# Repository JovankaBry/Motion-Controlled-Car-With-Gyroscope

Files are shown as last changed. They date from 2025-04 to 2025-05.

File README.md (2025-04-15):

# Embedded-System-Project
A motion-controlled car project using an MPU6050 gyroscope connected via wire to an Arduino, where hand tilts control the car’s direction.

How It Works:
- An MPU6050 sensor is mounted on a glove or handheld controller.
- The sensor detects the tilt of the hand (pitch and roll).
- These tilt values are sent to the Arduino over a wired connection (I2C).
- Based on the detected angle, the Arduino processes the data and controls the car's direction:
  - Tilt left → car turns left
  - Tilt right → car turns right
  - Tilt forward → car moves forward
  - Tilt backward → car reverses

Components Used:
-Arduino Nano
- MPU6050 Gyroscope & Accelerometer Module
- Motor Driver (e.g., L298N or similar)
- DC motors with wheels
- Battery 9V
- Jumper wires
- Chassis or 3D printed body

Features:
-Real-time motion control using hand gestures
-Wired I2C communication for low latency
-Simple and intuitive control system
-Expandable for wireless control (e.g., using NRF24L01 or Bluetooth)

Library:
For the sensor MPU-6050 a library is needed and the right library for that is MPU6050_Light from rfetick "https://github.com/rfetick/MPU6050_light"

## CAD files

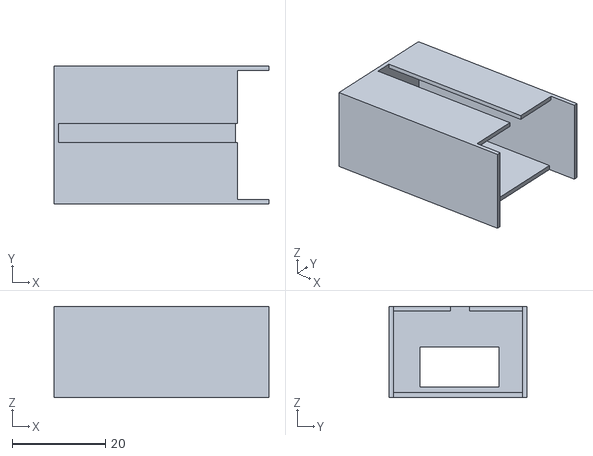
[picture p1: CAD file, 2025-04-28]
CAD-3D Parts/Additional Parts/Battery Pack.stl
46.0 x 29.5 x 19.5

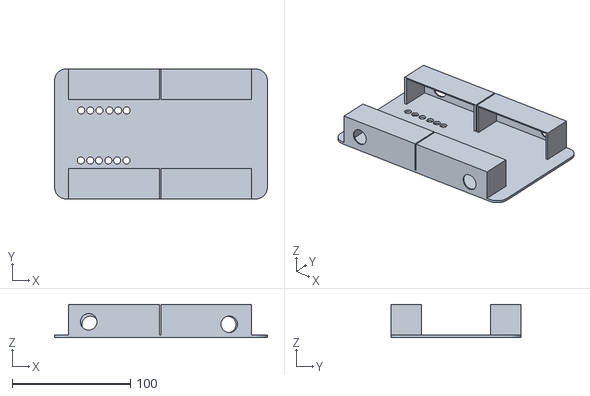
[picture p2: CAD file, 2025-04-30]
CAD-3D Parts/Prototype V2/Prototype V2.stl
180.0 x 110.0 x 28.0

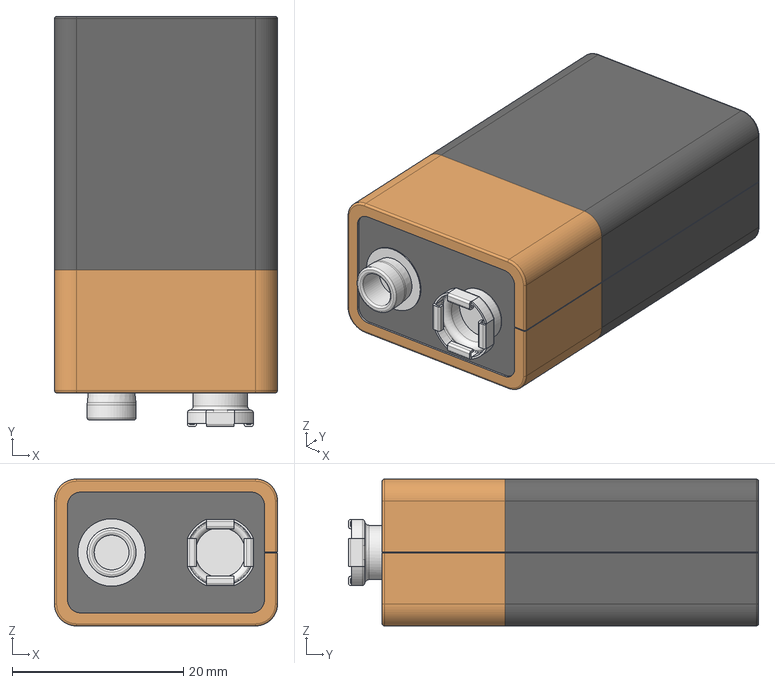
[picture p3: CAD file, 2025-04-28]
CAD-3D Parts/Additional Parts/9V-battery.stp
26.0 x 47.9 x 17.1 mm

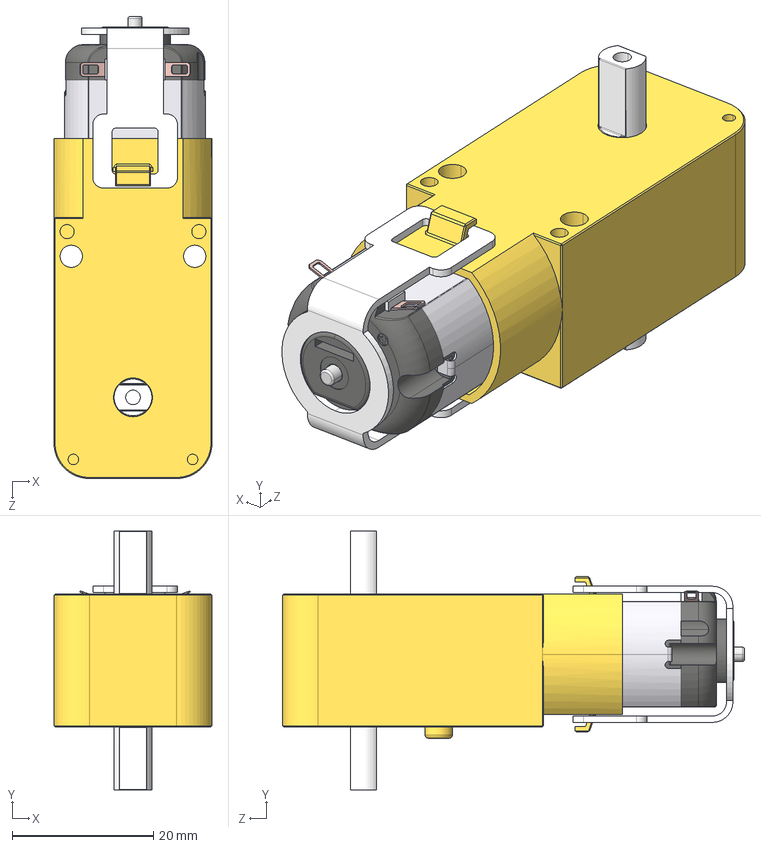
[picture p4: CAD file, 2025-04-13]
CAD-3D Parts/Additional Parts/Mini Gear DC Motor 6 V Yellow.STEP
22.4 x 36.7 x 65.5 mm
dc motor.stp
Nody
Axe
Belt

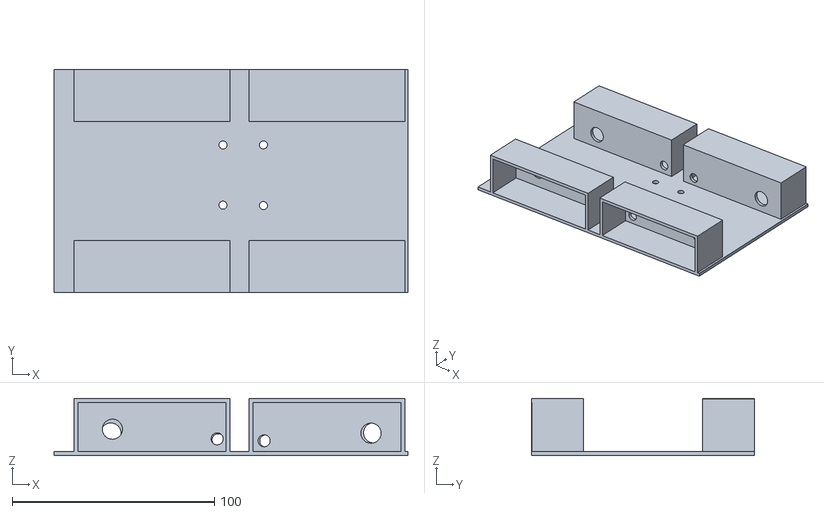
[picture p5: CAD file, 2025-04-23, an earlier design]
CAD-3D Parts/Prototype V1/Prototype1.stl
175.0 x 110.0 x 28.4

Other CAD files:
CAD-3D Parts/Transmitter Case/Transmitter case.dwg
CAD-3D Parts/Prototype V1/Protoype1.dwg
CAD-3D Parts/Prototype V2/Prototype V2.dwg

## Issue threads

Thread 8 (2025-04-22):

Reset Button must be added to MCU

JovankaBry, 2025-04-22:

JovankaBry, 2025-04-22:
button must be connected to RESET pin from MCU

JovankaBry, 2025-04-28:
reset button is not needed, considering the ardino nano isnt closed at all!

Closed 2025-04-28.

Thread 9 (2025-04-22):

On & Off

JovankaBry, 2025-04-22:
adding button/transistor/switch, so the motor can be deactivated

JovankaBry, 2025-04-24:
The idea is to use 1 transistor, and when a button is pressed, current flows through Base (PIN 2), ensuring the connection between Collector and Emitter

JovankaBry, 2025-04-24:
const int buttonPin = 6;
const int ledPin = 4;
int ledState = LOW;
int lastButtonState = HIGH;

void setup() {
  pinMode(ledPin, OUTPUT);
  pinMode(buttonPin, INPUT_PULLUP);
  digitalWrite(ledPin, ledState);
}

void loop() {
  int currentButtonState = digitalRead(buttonPin);

  if (lastButtonState == HIGH && currentButtonState == LOW) {
    ledState = !ledState;
    digitalWrite(ledPin, ledState);
    delay(200); // Simple debounce delay
  }

  lastButtonState = currentButtonState;
}

Closed 2025-05-07.

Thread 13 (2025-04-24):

Start to make Schematic

JovankaBry, 2025-04-24:
Schematic needs to be ordered around the middle of May

JovankaBry, 2025-04-24:
It can be ordered through. The price of the first order is 5€[Next PCB](https://www.nextpcb.com/pcb-quote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)

JovankaBry, 2025-04-24:
or [PCB Way](https://www.pcbway.com/orderonline.aspx)

JovankaBry, 2025-04-28:
started to make schamatic, need to be rechecked

Closed 2025-04-28.

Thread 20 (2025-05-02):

9V Battery Issues

JovankaBry, 2025-05-02:
idea is to change 9v batterie to 1.5v in series battery

Closed 2025-05-07.

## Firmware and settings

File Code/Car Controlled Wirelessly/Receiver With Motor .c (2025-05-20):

#include <SPI.h>
#include <nRF24L01.h>
#include <RF24.h>

RF24 radio(7, 8); // CE, CSN pins
const byte address[6] = "00001";

// Motor pins (using your exact setup)
const int motor1 = 2;
const int motor2 = 3;
const int motor3 = 5;
const int motor4 = 6;

struct GyroData {
  float angleX; // Left/Right tilt
  float angleY; // Forward/Backward tilt
};

void setup() {
  Serial.begin(9600);
  
  // Initialize motor pins
  pinMode(motor1, OUTPUT);
  pinMode(motor2, OUTPUT);
  pinMode(motor3, OUTPUT);
  pinMode(motor4, OUTPUT);
  
  // Initialize radio
  radio.begin();
  radio.openReadingPipe(0, address);
  radio.setPALevel(RF24_PA_MIN);
  radio.startListening();

  Serial.println("System Ready");
}

void stopMotors() {
  digitalWrite(motor1, LOW);
  digitalWrite(motor2, LOW);
  digitalWrite(motor3, LOW);
  digitalWrite(motor4, LOW);
}

void moveForward() {
  // Your exact forward pattern
  digitalWrite(motor1, LOW);
  digitalWrite(motor2, HIGH);
  digitalWrite(motor3, HIGH);
  digitalWrite(motor4, LOW);
  Serial.println("Moving Forward");
}

void moveForwardRight() {
  // Nyalakan roda depan kiri dulu
  digitalWrite(motor1, LOW);   // Depan kiri maju
  digitalWrite(motor2, HIGH);  // Belakang kiri mundur (untuk maju)
  
  // Delay sebentar sebelum nyalakan roda kanan
  delay(100); // Delay 100ms

  digitalWrite(motor3, HIGH);  // Depan kanan maju
  digitalWrite(motor4, LOW);   // Belakang kanan mundur (untuk maju)

  Serial.println("Moving Forward Right (dengan delay motor3)");
}

void moveForwardLeft() {
  // Nyalakan sisi kanan dulu
  digitalWrite(motor3, HIGH);  // Depan kanan maju
  digitalWrite(motor4, LOW);   // Belakang kanan bantu maju

  delay(100); // Delay sebelum sisi kiri nyala

  digitalWrite(motor1, LOW);   // Depan kiri maju
  digitalWrite(motor2, HIGH);  // Belakang kiri bantu maju

  Serial.println("Moving Forward Left");
}

void moveBackward() {
  // Inverse of your forward pattern
  digitalWrite(motor1, HIGH);
  digitalWrite(motor2, LOW);
  digitalWrite(motor3, LOW);
  digitalWrite(motor4, HIGH);
  Serial.println("Moving Backward");
}

void moveBackwardRight() {
  // Nyalakan sisi kiri dulu (mundur)
  digitalWrite(motor1, HIGH);  // Depan kiri mundur
  digitalWrite(motor2, LOW);   // Belakang kiri bantu mundur

  delay(100); // Delay sebelum sisi kanan nyala

  digitalWrite(motor3, LOW);   // Depan kanan mundur
  digitalWrite(motor4, HIGH);  // Belakang kanan bantu mundur

  Serial.println("Moving Backward Right");
}

void moveBackwardLeft() {
  // Nyalakan sisi kanan dulu (mundur)
  digitalWrite(motor3, LOW);   // Depan kanan mundur
  digitalWrite(motor4, HIGH);  // Belakang kanan bantu mundur

  delay(100); // Delay sebelum sisi kiri nyala

  digitalWrite(motor1, HIGH);  // Depan kiri mundur
  digitalWrite(motor2, LOW);   // Belakang kiri bantu mundur

  Serial.println("Moving Backward Left");
}

void turnRight() {
  // Left side forward, right side backward (sharp turn)
  digitalWrite(motor1, LOW);
  digitalWrite(motor2, HIGH);
  digitalWrite(motor3, LOW);
  digitalWrite(motor4, HIGH);
  Serial.println("Turning Right");
}

void turnLeft() {
  // Right side forward, left side backward (sharp turn)
  digitalWrite(motor1, HIGH);
  digitalWrite(motor2, LOW);
  digitalWrite(motor3, HIGH);
  digitalWrite(motor4, LOW);
  Serial.println("Turning Left");
}

void loop() {
  if (radio.available()) {
    GyroData data;
    radio.read(&data, sizeof(data));

    // Invert angleY to fix left/right confusion
    data.angleY = -data.angleY;

    stopMotors();

    // angleX = forward/backward tilt
    // angleY = left/right tilt
    if (data.angleX > 15 && data.angleY > 15) {
      moveForwardRight();
    }
    else if (data.angleX > 15 && data.angleY < -15) {
      moveForwardLeft();
    }
    else if (data.angleX < -15 && data.angleY > 15) {
      moveBackwardRight();
    }
    else if (data.angleX < -15 && data.angleY < -15) {
      moveBackwardLeft();
    }
    else if (data.angleX > 15) {
      moveForward();
    }
    else if (data.angleX < -15) {
      moveBackward();
    }
    else if (data.angleY > 15) {
      turnRight();
    }
    else if (data.angleY < -15) {
      turnLeft();
    }
    else {
      stopMotors();
      Serial.println("Stopped");
    }
  }
}

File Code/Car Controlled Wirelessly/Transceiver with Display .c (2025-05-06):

#include <SPI.h>
#include <nRF24L01.h>
#include <RF24.h>
#include <Wire.h>
#include <MPU6050_light.h>
#include <U8g2lib.h>

// NRF24 Setup
RF24 radio(7, 8); // CE, CSN for Uno/Nano
const byte address[6] = "00001";

// MPU6050 Setup
MPU6050 mpu(Wire);
unsigned long timer = 0;

// OLED Setup
U8G2_SH1106_128X64_NONAME_1_HW_I2C u8g2(U8G2_R0, /* reset=*/ U8X8_PIN_NONE);

// Button Setup
const int buttonPin = 3; // Button to GND with internal pull-up
unsigned long buttonPressTime = 0;
bool resetTriggered = false;

// Data structure
struct GyroData {
  float angleX;
  float angleY;
  float angleZ;
};

void softReset() {
  asm volatile ("jmp 0"); // Software reset
}

void checkReset() {
  static bool buttonActive = false;
  
  if (digitalRead(buttonPin) == LOW) { // Button pressed
    if (!buttonActive) {
      buttonActive = true;
      buttonPressTime = millis();
    }
    
    // Check if held for 5 seconds
    if (millis() - buttonPressTime > 5000 && !resetTriggered) {
      u8g2.firstPage();
      do {
        u8g2.setFont(u8g2_font_ncenB08_tr);
        u8g2.drawStr(20, 30, "Resetting...");
      } while (u8g2.nextPage());
      delay(500);
      resetTriggered = true;
      softReset();
    }
  } else {
    buttonActive = false;
  }
}

void Introscreen() {
  u8g2.firstPage();
  do {
    u8g2.setFont(u8g2_font_ncenB08_tr);
    u8g2.drawStr(10, 15, "Embedded System");
    u8g2.drawStr(40, 30, "Projekt");
    u8g2.drawStr(35, 45, "Sose 2025");
  } while (u8g2.nextPage());
  delay(2000);
}

void showWelcomeScreen() {
  u8g2.firstPage();
  do {
    u8g2.setFont(u8g2_font_ncenB08_tr);
    u8g2.drawStr(5, 15, "Herzlich Wilkommen");
    u8g2.drawStr(23, 30, "Bitte Druecken");
    u8g2.drawStr(30, 45, "zum Starten");
  } while (u8g2.nextPage());
}

void setup() {
  Serial.begin(9600);
  Wire.begin();
  pinMode(buttonPin, INPUT_PULLUP);

  // Initialize OLED
  u8g2.begin();

  // Initialize MPU6050
  byte status = mpu.begin();
  Serial.print(F("MPU6050 status: "));
  Serial.println(status);
  while(status != 0) { 
    // Show error if MPU fails to initialize
    u8g2.firstPage();
    do {
      u8g2.setFont(u8g2_font_ncenB08_tr);
      u8g2.drawStr(15, 30, "MPU6050 Error!");
      u8g2.drawStr(10, 45, "Check Connection");
    } while (u8g2.nextPage());
    delay(1000);
  }

  Introscreen();

  // Wait for button press to continue
  bool waitingForButton = true;
  while(waitingForButton) {
    checkReset(); // Check for reset during wait
    showWelcomeScreen();
    
    if(digitalRead(buttonPin) == LOW) {
      delay(50); // Debounce
      if(digitalRead(buttonPin) == LOW) {
        waitingForButton = false;
      }
    }
    mpu.update(); // Keep MPU updated
  }

  // Calibration
  Serial.println(F("Calculating offsets, do not move MPU6050"));
  u8g2.firstPage();
  do {
    u8g2.setFont(u8g2_font_ncenB08_tr);
    u8g2.drawStr(5, 30, "Calculating MPU6050");
    u8g2.drawStr(20, 45, "DO NOT MOVE!!!");
  } while (u8g2.nextPage());
  
  delay(1000);
  mpu.calcOffsets();
  Serial.println("Done!\n");

  // Ready message
  u8g2.firstPage();
  do {
    u8g2.setFont(u8g2_font_ncenB08_tr);
    u8g2.drawStr(20, 30, "Device Is Ready");
  } while (u8g2.nextPage());
  delay(2000);

  // Radio initialization
  if (!radio.begin()) {
    Serial.println("Radio initialization failed!");
    u8g2.firstPage();
    do {
      u8g2.setFont(u8g2_font_ncenB08_tr);
      u8g2.drawStr(15, 30, "Radio Error!");
      u8g2.drawStr(10, 45, "Check NRF24");
    } while (u8g2.nextPage());
    while(1); // Halt on radio failure
  }
  Serial.println("Radio initialized successfully");
  radio.openWritingPipe(address);
  radio.setPALevel(RF24_PA_MIN);
  radio.stopListening();
}

void loop() {
  checkReset(); // Continuous reset check
  
  mpu.update();

  if ((millis() - timer) > 20) { // 50Hz update rate
    GyroData data = {mpu.getAngleX(), mpu.getAngleY(), mpu.getAngleZ()};
    bool success = radio.write(&data, sizeof(data));

    // OLED Display Update
    u8g2.firstPage();
    do {
      u8g2.setFont(u8g2_font_6x10_tr);
      u8g2.setCursor(0, 12); 
      u8g2.print("X: "); u8g2.print(data.angleX, 1);
      u8g2.setCursor(0, 24); 
      u8g2.print("Y: "); u8g2.print(data.angleY, 1);
      u8g2.setCursor(0, 36); 
      u8g2.print("Z: "); u8g2.print(data.angleZ, 1);
      u8g2.setCursor(0, 48); 
      u8g2.print("TX: "); u8g2.print(success ? "OK" : "Fail");
    } while (u8g2.nextPage());

    // Serial Monitor Output
    Serial.print("X: ");
    Serial.print(data.angleX);
    Serial.print(" Y: ");
    Serial.print(data.angleY);
    Serial.print(" Z: ");
    Serial.print(data.angleZ);
    Serial.print(" Transmission: ");
    Serial.println(success ? "OK" : "Failed");

    timer = millis();
  }
}

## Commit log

2025-04-13 Create Cad-3D File
    3D Files from CAD for the Project
2025-04-13 DC Motor CAD
2025-04-13 DC Motor 6V CAD 3D
    [Mini Gear DC Motor 6 V Yellow.STEP]
2025-04-13 Made simple board for the project
    the board has 4 small rooms in the bottom size, the rooms are being used for the 4 DC motors,
    [Prototyp1.dwg]
2025-04-13 Delete CAD-3D Parts/test
    ONLY TEST
2025-04-15 Schematic & PCB for the "Piggy Bag" of the Arduino Nano
2025-04-15 Code for direction for Prototype 1
2025-04-15 added turn left while going straight
    added turn left while going straight, because when only LEFT mode is activated, the car will start spinning around, so the motor on the other side need to be adjusted
2025-04-15 Added STL file for 3D Printing
    [Prototyp1.stl]
2025-04-15 Simple Code for turning on LED
2025-04-15 LED turns on when x axis is greater than 10
2025-04-15 Create NRF24L01 wireless module
    code and library needs to be added & made for this project
2025-04-22 Rename Directions to Motor Directions
2025-04-22 Created Prototype1
2025-04-23 Updated 3D files
    [Prototype1.stl, Protoype1.2.dwg]
2025-04-24 Prototype V1
2025-04-24 Created Prototype V1
2025-04-24 Create Prototype V2
2025-04-24 Rename Prototype /Prototype V2 to Prototype /Prototype V2 /About Prototype V2 .txt
2025-04-24 Update and rename te to About Prototype V1 .txt
2025-04-24 These are the following files for Prototype 1
    [Prototype1.stl, Protoype1.dwg]
2025-04-27 Created Prototype 2
2025-04-27 Created Protype 2
    [Prototype2.dwg]
2025-04-27 Added Prototype 2 stl
    [Prototype2.stl]
2025-04-27 Created Prototype2
    [Prototype2.stl]
2025-04-27 added DWG Prototype 2
    [Prototype2.dwg]
2025-04-27 Create Receiver With Motor .c
2025-04-27 Update Receiver With Motor .c
2025-04-28 Added Prototype 2.1
    Seperated Battry pack
    [Prototype 2.1.dwg, Prototype V2.2.stl]
2025-04-28 Added 3D Additional Parts
    [9V-battery.stp, Mini Gear DC Motor 6 V Yellow.STEP]
2025-04-28 Create Prototype V1
2025-04-28 Added Prototype 1
    [Prototype1.stl, Protoype1.dwg]
2025-04-28 Added Prototype 2
    [Prototype V2.dwg, Prototype V2.stl]
2025-04-28 Added Battery pack for Prototype V2
    [Battery Pack.stl]
2025-04-28 Added Prototype V1 Schematic
    [PCB1.PcbDoc, PCB_Motor.PrjPcb, Prototype V1.SchDoc]
2025-04-30 Added Prototype V2
    [Prototype V2.stl]
2025-04-30 Added DWG
    [Prototype V2.dwg]
2025-05-04 Create 3D CAD
2025-05-05 WOrking with Device is Ready in display
2025-05-05 Update Transceiver with Display. c
    added 5s timer for device is ready
2025-05-05 Update Transceiver with Display. c
    Added button to start
2025-05-05 Update Transceiver with Display. c
    Added Button and Reset function
2025-05-07 New codew for prototype V2
2025-05-10 Uploaded Schematic PCB for Transmitter
    [PCB1.PcbDoc, PCB_Motor.PrjPcb, Prototype V1.SchDoc]
2025-05-11 Updatet Schematic for Transmitter
    [PCB1.PcbDoc, PCB_Motor.PrjPcb, Prototype V1.SchDoc]
2025-05-11 Updated Schematic and Layout for Tramitter
    [PCB1.PcbDoc, PCB_Motor.PrjPcb]
2025-05-11 Added .cam Gerber file
2025-05-11 Added Battery Voltage detector
    [PCB1.PcbDoc, PCB_Motor.PrjPcb, Prototype V1.SchDoc]
2025-05-11 Added Gerber File
    [PCB1.GBL, PCB1.GBP, PCB1.GBS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]
2025-05-11 Added PCB Tramitter .step & updated transmitter case.dwg
    [PCB_Motor.PrjPcb]
2025-05-12 Updated Transmitter case.dwg
2025-05-16 Deleted Unneeded file
    [PCB1.PcbDoc, PCB_Motor.PrjPcb, Prototype V1.SchDoc]
2025-05-16 Added Schematic for motor Receiver
    [PCB_Motor_Receiver.PrjPcb, PCB_Receiver.PcbDoc, Receiver.SchDoc]
2025-05-16 Updated Schematic for Receiver with motor
    [PCB_Motor_Receiver.PrjPcb, PCB_Receiver.PcbDoc, Receiver.SchDoc]
2025-05-16 Finished pcb for Motor Receiver
    [PCB_Motor_Receiver.PrjPcb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]
2025-05-20 Updated width +3V3 Width to 1mm
    [PCB1.PcbDoc]
2025-05-20 Added Transmitter V2
    [PCB_Transmitter_V2.PcbDoc, Transmitter V2.PrjPcb, Transmitter V2.SchDoc]
2025-05-20 Schematic finsihed, but needs to be rechecked again
    [Transmitter V2.PrjPcb, Transmitter V2.SchDoc]
2025-05-21 Finished building Transmitter Prototype V2
    [PCB_Transmitter_V2.PcbDoc, Transmitter V2.PrjPcb, Transmitter V2.SchDoc]
2025-05-21 Changed The LED On&Off Status
    [PCB_Transmitter_V2.PcbDoc, Transmitter V2.SchDoc]
2025-05-21 Added Project Outputs for Transmitter V2
    [PCB_Transmitter_V2.GBL, PCB_Transmitter_V2.GBP, PCB_Transmitter_V2.GBS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]
2025-05-22 Added Motor Receiver V2
    [PCB_Receiver_V2.PcbDoc, Project_Motor_V2.PrjPcb, Receiver V2.SchDoc]
2025-05-22 Finished Receiver V2 Schematic
    [PCB_Receiver_V2.PcbDoc, Project_Motor_V2.PrjPcb, Receiver V2.SchDoc]
2025-05-22 Finished Receiver V2
    [PCB_Receiver_V2.GBL, PCB_Receiver_V2.GBO, PCB_Receiver_V2.GBP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]
